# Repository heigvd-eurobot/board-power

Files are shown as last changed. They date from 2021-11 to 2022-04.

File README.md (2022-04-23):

# CRH Power Supply Board

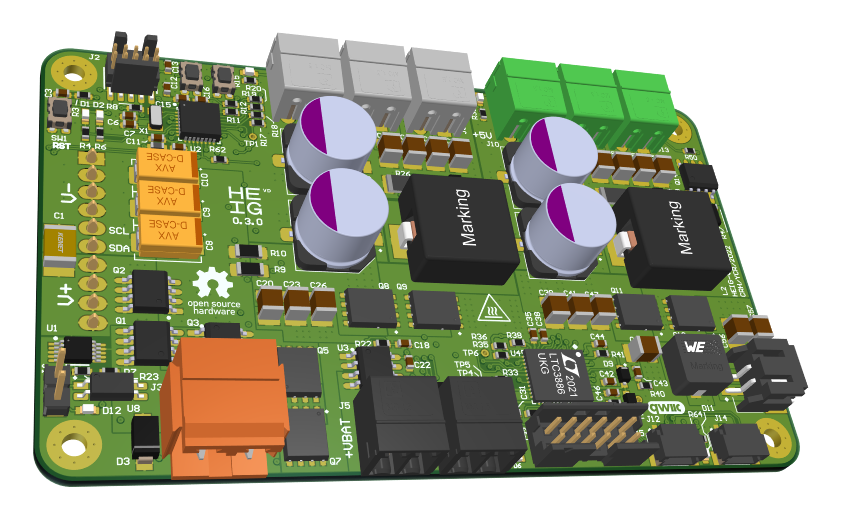
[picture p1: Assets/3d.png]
3D View


The Main Power Supply Board is a highly compact electronic board made to power up an embedded robot from a DJI Mavic 2 Battery (4-cell Li-Po) or an external power supply.

**The schematics** is available [here](Assets/schemtatics.pdf).

The board provides:

- 5 V @ 10 A Output
- 10..12 V @ 10 A Configurable Output
- 3.3 V @ 4 A Output (that may power the Qwiic System)

I2C Qwiic connectors can control the output voltages and monitor the flowing current in all outputs. An emergency switch connector will shut down all power voltages.

## Detailed specifications

- Mechanical
  - 95x58 mm
  - 4x M2.5 fixation holes
- Connectors
  - 1x 2-pin 7.62 mm External Power
  - 2x 2-pin 3.5 mm Black Battery output (on/off)
  - 2x 2-pin 3.5 mm Green 5V Output (on/off)
  - 1x 2-pin 3.5 mm Green 5V Output (on/off)
  - 3x 2-pin 3.5 mm Gray 10..12V Output (on/off)
  - 1x 12-pin LTPower debug port (For DC1613 debug probe)
  - 1x 10-pin SWD debug port for the MCU (ATSAMD20E)
  - 1x 10-pin DJI Mavic Zoom battery port
  - 1x 2-pin Emergency stop
- Pushbuttons
  - 1x Reset
  - 1x Manual Enable/disable 10..12V
  - 1x Manual Enable/disable 5V
- Monitoring
  - 5V Voltage
  - 10..12V Voltage
  - Battery voltage
  - 3.3V Voltage
  - 5V Current
  - 10..12V Current
  - Total Current consumption
  - Efficiency monitoring
  - Total Power consumption
  - I2C DJI Mavic BMS
    - Cell voltage
    - Battery cycles
    - Charge state
    - Battery life status
    - ...
- Control
  - LTC3886-1
  - ATSAMD20E
- PCB
  - 4L 6C 1.55 mm

## Revisions

### 0.1.0 Alpha (2021-10-10)

Errata:

- LTC3886 I2C address not configured (set to 0x00)
- INA381 current monitoring not working
- SCL/SDA inverted on Qwiic connectors
- Q6, Q15 should be P-MOS not N-MOS
- Missing thermal relief on most pads
- Some vias are not tamped
- Missing testpoints
- Oshpark purple PCB soldermask not good

### 0.2.0 Alpha

- Switch Frequency and phase EEPROM configured
- I2C configured by resistor
- Add testpoints
- Changed PCB color to green
- 3.3V divisor configured by E12 series instead of E96
- Add RC filter on INA381

### 0.3.0 Alpha (2022-04-23)

- Fix components absolute maximum voltage from 20ish to 40V.
- Add a I2C power monitoring and switch
- Add a 3.3V connector
- Add Hardware ESTOP (Emergency Stop) through an optocoupler
- Add ESTOP LED
- Change P-MOS switch for VBAT outputs for N-MOS
- Change the VBAT current monitoring IC for a Hall effect sensor
- Change number of layers from 4 to 6
- Fix via in pad issues with filled via (Eurocircuits option)
- Add vias in fixation holes
- Change the VEXT/VBAT switch IC for a more specialized one
- Fix LTC3886 resistors and I2C address

## Setup instructions

### Mise en service prototype

1. Supprimer R22 car le INA381 pose problème et on retrouve 4V sur pin 7
2. Éviter la série E96, R45 = 24k et R46 = 75k -> (75/24 + 1) * 0.8 = 3.3000000000000003
3. R51 à 8k2, ca devrait le faire
4. Q4 n'est pas nécessaire il empeche d'avoir de la tension sur SENSE, on peut le supprimer et mettre une zéro ohm entre S et D
5. Mettre leds vertes partout sauf sur D2 en rouge
6. Bug sur I2C, inversion SDA/SCL

Vérifier C57 ou C58 ? Hein ?

### Première mise sous tension

0. Contôle visuel sous loupe
1. Alimenter J3, limité en courant à 10mA, monter jusqu'à 15V. Vérifier la présence du 3.3V sur C58
2. Se connecter sur J9 avec le DC1613 et LTPowerPlay
3. Configurer le LTC3886
4. Se connecter sur le MCU
5. Charger un programme de base (celui qui active le 5V et le 12V)
6. Vérifier les tensions de sorties 5V et 12V
7. CC SB1 pour sauvegarder la config

## License Information

This product is **open-source**

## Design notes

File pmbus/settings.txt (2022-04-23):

#LTC PMBus Project Text File Version:1.1
#Checksum:0x6FEE
# This File is a text (machine readable) listing of all writable register values
# in your project (.proj file
# 
# NOTE: These comments are included for your benefit.  You may safely remove any line
# that starts with the character '#'
# 
# The format of this file is as follows:
# 
# Format Rules that Apply to all Versions:
#  * The first line of this file will always include a unique identifer indicating 
#    the particular version of the text file format as a comment line.
#      Example: '#LTC PMBus Project Text File Version:1.1'
# Version 1.1 format rules:
#  * The '#' character denotes a comment that should be ignored by software
#  * The next comment line (after the mandatory version line) shows the
#    checksum: 
#      Example: '#Checksum:0xAFAFAFAF'
#  * The last comment line before the register values shows the column headers: 
#      Example: '#7-Bit Address,Page,Write Protocol,Register Command Code,[DataByteHi]DataByteLo,RegisterName'
#  * Each following line contains the values for one specific register
# 
# Examples:
# 
# The following line indicates that Global Register VIN_OV_FAULT_RESPONSE_GLOBAL of the
# device at 7-bit I2C address 0x5C should be written using the Write Byte(WB)
# protocol with the command code 0x56 and the data byte 0x00
# 
# #7-Bit Address,Page,Write Protocol,Register Command Code,[DataByteHi]DataByteLo,RegisterName
# 0x5C,-1,WB,0x56,0x00,VIN_OV_FAULT_RESPONSE_GLOBAL
# 
# NOTE: The I2C transaction your software would generate is as follows:
#  * <StartCondition>
#  * 0xB8 (7-bit I2C address 0x5C with the write bit set 101 1100-0)
#  * 0x56 (The 8-bit command code for the register VIN_OV_FAULT_RESPONSE_GLOBAL)
#  * 0x00 (the data byte value for VIN_OV_FAULT_RESPONSE_GLOBAL)
#  * <StopCondition>
# NOTE: There is no need to set the PAGE register, because this is a global register
#       as indicated by Page='-1'
# NOTE: The I2C primitives necessary to execute this 'Write Byte' protocol are
#       defined in the SMBUS(TM) standard
# 
# The following line indicates the paged TON_RISE register for Page 3 of the device
# at 7-bit I2C address 0x5D should be written using the Write Word(WW) protocol with
# the command code 0x61 and the data word 0xDA80 (the low data byte byte is 0x80)
# 
# #7-Bit Address,Page,Write Protocol,Register Command Code,[DataByteHi]DataByteLo,RegisterName
# 0x5D,3,WW,0x61,0xDA80,TON_RISE
# 
# NOTE: The I2C transaction you would need to generate to write this to the device is as follows:
# 
#  * <StartCondition>
#  * 0xBA (7-bit I2C address 0x5D with the write bit set 101 1101-0)
#  * 0x00 (The 8-bit command code for the PAGE register)
#  * 0x03 (data byte indicating desired Page=3)
#  * <StopCondition>
# 
#  * <StartCondition>
#  * 0xBA (7-bit I2C address 0x5D with the write bit set 101 1101-0)
#  * 0x61 (The 8-bit command code for the global register VIN_OV_FAULT_RESPONSE_GLOBAL)
#  * 0x80 (Lo Data byte representing the desired value for the paged register TON_RISE)
#  * 0xDA (Hi Data byte representing the desired value for the paged register TON_RISE)
#  * <StopCondition>
# 
# NOTE: The I2C primitives necessary to execute this 'Write Word' protocol are defined in the SMBUS(TM) standard
# NOTE: The page register only needs to be written when you need to address a different page
# 
# 
# -----------------------------------
# NOTES ON Checksum Algorithm
# -----------------------------------
# The GUI Computes a simple 16-bit checksum for each text file it exports.
# This checksum is calculated according to the following algorithm:
# 
# Initialize the 16-bit Checksum=0
# For each line of the text file that includes a register value (like the above examples):
#   Checksum = Checksum + <7-bit address>
#   Checksum = Checksum + <page>
#   Checksum = Checksum + <command code>
#   Checksum = Checksum + <lo data byte>
#   Checksum = Checksum + <hi data byte> (add 0, or simply skip for single byte values)
# Checksum = 2's complement of Checksum
# 
# How to Verify that the Checksum is Valid when reading a text file:
# Parse the checksum reported by this file (i.e. Checksum:0xFFFD) -- call this ReportedChecksum
# Initialize a variable SumOfBytes=0
# For each line of the text file that includes a register value:
#   SumOfBytes = SumOfBytes + <7-bit address>
#   SumOfBytes = SumOfBytes + <page>
#   SumOfBytes = SumOfBytes + <command code>
#   SumOfBytes = SumOfBytes + <lo data byte>
#   SumOfBytes = SumOfBytes + <hi data byte> (add 0, or simply skip for single byte values)
# If the lowest 16-bits of SumOfBytes + ReportedChecksum == 0, the checksum is good
# Otherwise the checksum is bad.
# 
# For Example: If your SumOfBytes was computed as 0x3 and 
# the ReportedChecksum in the file was 0xFFFD.
#   0x3 + 0xFFFD = 0x10000
#   The lowest 16-bits are 0, so this cheksum is good.
# 
# 
#7-Bit Address,Page,Write Protocol,Register Command Code,[DataByteHi]DataByteLo,RegisterName
0x00,-1,WB,0x10,0x00,WRITE_PROTECT 
0x00,-1,WW,0x33,0xFABC,FREQUENCY_SWITCH_LTC3886 
0x00,-1,WW,0x35,0xD360,VIN_ON 
0x00,-1,WW,0x36,0xD320,VIN_OFF 
0x00,-1,WW,0x55,0xDA80,VIN_OV_FAULT_LIMIT 
0x00,-1,WW,0x58,0xD340,VIN_UV_WARN_LIMIT 
0x00,-1,WW,0x5D,0xDA80,IIN_OC_WARN_LIMIT 
0x00,-1,WSM,0x7C,0x00,MASK_STATUS_INPUT 
0x00,-1,WSM,0x7E,0x00,MASK_STATUS_CML 
0x00,-1,WW,0xB0,0x0000,USER_DATA_00 
0x00,-1,WW,0xB2,0x0000,USER_DATA_02 
0x00,-1,WW,0xB4,0x0000,USER_DATA_04 
0x00,-1,WB,0xD1,0x61,MFR_CONFIG_ALL_LTC3886 
0x00,-1,WB,0xE6,0x4F,MFR_ADDRESS_LTC 
0x00,-1,WW,0xE8,0xC300,MFR_IIN_CAL_GAIN_LTC 
0x00,-1,WB,0xF5,0x10,MFR_PWM_CONFIG_LTC3886 
0x00,-1,WW,0xF7,0xC300,MFR_RVIN 
0x00,0,WB,0x01,0x80,OPERATION 
0x00,0,WB,0x02,0x1E,ON_OFF_CONFIG 
0x00,0,WW,0x21,0xC000,VOUT_COMMAND 
0x00,0,WW,0x24,0xE000,VOUT_MAX 
0x00,0,WW,0x25,0xC99A,VOUT_MARGIN_HIGH 
0x00,0,WW,0x26,0xB666,VOUT_MARGIN_LOW 
0x00,0,WW,0x27,0xAA00,VOUT_TRANSITION_RATE 
0x00,0,WW,0x38,0xC300,IOUT_CAL_GAIN 
0x00,0,WW,0x40,0xD333,VOUT_OV_FAULT_LIMIT 
0x00,0,WB,0x41,0xB8,VOUT_OV_FAULT_RESPONSE 
0x00,0,WW,0x42,0xCE66,VOUT_OV_WARN_LIMIT 
0x00,0,WW,0x43,0xB19A,VOUT_UV_WARN_LIMIT 
0x00,0,WW,0x44,0xACCD,VOUT_UV_FAULT_LIMIT 
0x00,0,WB,0x45,0xB8,VOUT_UV_FAULT_RESPONSE 
0x00,0,WW,0x46,0xD300,IOUT_OC_FAULT_LIMIT 
0x00,0,WB,0x47,0x00,IOUT_OC_FAULT_RESPONSE 
0x00,0,WW,0x4A,0xD280,IOUT_OC_WARN_LIMIT 
0x00,0,WW,0x4F,0xEA80,OT_FAULT_LIMIT_PAGED 
0x00,0,WB,0x50,0xB8,OT_FAULT_RESPONSE_PAGED 
0x00,0,WW,0x51,0xEA58,OT_WARN_LIMIT_PAGED 
0x00,0,WW,0x53,0xE580,UT_FAULT_LIMIT_PAGED 
0x00,0,WB,0x54,0xB8,UT_FAULT_RESPONSE_PAGED 
0x00,0,WB,0x56,0x80,VIN_OV_FAULT_RESPONSE_PAGED 
0x00,0,WW,0x60,0x8000,TON_DELAY 
0x00,0,WW,0x61,0xD200,TON_RISE 
0x00,0,WW,0x62,0xD280,TON_MAX_FAULT_LIMIT 
0x00,0,WB,0x63,0xB8,TON_MAX_FAULT_RESPONSE 
0x00,0,WW,0x64,0x8000,TOFF_DELAY 
0x00,0,WW,0x65,0xD200,TOFF_FALL 
0x00,0,WW,0x66,0xF258,TOFF_MAX_WARN_LIMIT 
0x00,0,WSM,0x7A,0x00,MASK_STATUS_VOUT 
0x00,0,WSM,0x7B,0x00,MASK_STATUS_IOUT 
0x00,0,WSM,0x7D,0x00,MASK_STATUS_TEMP 
0x00,0,WSM,0x80,0x11,MASK_STATUS_MFR_SPECIFIC_LTC388X 
0x00,0,WW,0xB1,0x84DA,USER_DATA_01 
0x00,0,WW,0xB3,0x0000,USER_DATA_03 
0x00,0,WB,0xD0,0x1D,MFR_CHAN_CONFIG_LTC388X 
0x00,0,WW,0xD2,0x6993,MFR_GPIO__SLASH__FAULT_PROPAGATE_LTC388X 
0x00,0,WB,0xD3,0x70,MFR_PWM_COMP 
0x00,0,WB,0xD4,0xC1,MFR_PWM_MODE_LTC3886 
0x00,0,WB,0xD5,0xC0,MFR_GPIO__SLASH__FAULT_RESPONSE_LTC388X 
0x00,0,WW,0xDB,0xFABC,MFR_RETRY_DELAY_LTC_PAGED 
0x00,0,WW,0xDC,0xFBE8,MFR_RESTART_DELAY_LTC_PAGED 
0x00,0,WW,0xF6,0x0F3C,MFR_IOUT_CAL_GAIN_TC 
0x00,0,WW,0xF8,0x4000,MFR_TEMP_1_GAIN 
0x00,0,WW,0xF9,0x8000,MFR_TEMP_1_OFFSET 
0x00,0,WB,0xFA,0x80,MFR_RAIL_ADDRESS_LTC 
0x00,1,WB,0x01,0x80,OPERATION 
0x00,1,WB,0x02,0x1E,ON_OFF_CONFIG 
0x00,1,WW,0x21,0x5000,VOUT_COMMAND 
0x00,1,WW,0x24,0x5800,VOUT_MAX 
0x00,1,WW,0x25,0x5400,VOUT_MARGIN_HIGH 
0x00,1,WW,0x26,0x4C00,VOUT_MARGIN_LOW 
0x00,1,WW,0x27,0xAA00,VOUT_TRANSITION_RATE 
0x00,1,WW,0x38,0xC300,IOUT_CAL_GAIN 
0x00,1,WW,0x40,0x5800,VOUT_OV_FAULT_LIMIT 
0x00,1,WB,0x41,0xB8,VOUT_OV_FAULT_RESPONSE 
0x00,1,WW,0x42,0x5600,VOUT_OV_WARN_LIMIT 
0x00,1,WW,0x43,0x4A00,VOUT_UV_WARN_LIMIT 
0x00,1,WW,0x44,0x4800,VOUT_UV_FAULT_LIMIT 
0x00,1,WB,0x45,0xB8,VOUT_UV_FAULT_RESPONSE 
0x00,1,WW,0x46,0xD300,IOUT_OC_FAULT_LIMIT 
0x00,1,WB,0x47,0x00,IOUT_OC_FAULT_RESPONSE 
0x00,1,WW,0x4A,0xD280,IOUT_OC_WARN_LIMIT 
0x00,1,WW,0x4F,0xEAD0,OT_FAULT_LIMIT_PAGED 
0x00,1,WB,0x50,0xB8,OT_FAULT_RESPONSE_PAGED 
0x00,1,WW,0x51,0xEA58,OT_WARN_LIMIT_PAGED 
0x00,1,WW,0x53,0xE580,UT_FAULT_LIMIT_PAGED 
0x00,1,WB,0x54,0xB8,UT_FAULT_RESPONSE_PAGED 
0x00,1,WB,0x56,0x80,VIN_OV_FAULT_RESPONSE_PAGED 
0x00,1,WW,0x60,0x8000,TON_DELAY 
0x00,1,WW,0x61,0xD200,TON_RISE 
0x00,1,WW,0x62,0xD280,TON_MAX_FAULT_LIMIT 
0x00,1,WB,0x63,0xB8,TON_MAX_FAULT_RESPONSE 
0x00,1,WW,0x64,0x8000,TOFF_DELAY 
0x00,1,WW,0x65,0xD200,TOFF_FALL 
0x00,1,WW,0x66,0xF258,TOFF_MAX_WARN_LIMIT 
0x00,1,WSM,0x7A,0x00,MASK_STATUS_VOUT 
0x00,1,WSM,0x7B,0x00,MASK_STATUS_IOUT 
0x00,1,WSM,0x7D,0x00,MASK_STATUS_TEMP 
0x00,1,WSM,0x80,0x11,MASK_STATUS_MFR_SPECIFIC_LTC388X 
0x00,1,WW,0xB1,0x4A5F,USER_DATA_01 
0x00,1,WW,0xB3,0x0000,USER_DATA_03 
0x00,1,WB,0xD0,0x1D,MFR_CHAN_CONFIG_LTC388X 
0x00,1,WW,0xD2,0x6993,MFR_GPIO__SLASH__FAULT_PROPAGATE_LTC388X 
0x00,1,WB,0xD3,0x70,MFR_PWM_COMP 
0x00,1,WB,0xD4,0xC1,MFR_PWM_MODE_LTC3886 
0x00,1,WB,0xD5,0xC0,MFR_GPIO__SLASH__FAULT_RESPONSE_LTC388X 
0x00,1,WW,0xDB,0xFABC,MFR_RETRY_DELAY_LTC_PAGED 
0x00,1,WW,0xDC,0xFBE8,MFR_RESTART_DELAY_LTC_PAGED 
0x00,1,WW,0xF6,0x0F3C,MFR_IOUT_CAL_GAIN_TC 
0x00,1,WW,0xF8,0x4000,MFR_TEMP_1_GAIN 
0x00,1,WW,0xF9,0x8000,MFR_TEMP_1_OFFSET 
0x00,1,WB,0xFA,0x80,MFR_RAIL_ADDRESS_LTC

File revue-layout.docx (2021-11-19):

Carte puissance

Remarques :

- La carte est dense et il y a beaucoup de puissance à dissiper. Je n’ai pas encore eu le temps de contrôler cette partie.

# | Quand | Quoi | Résolut

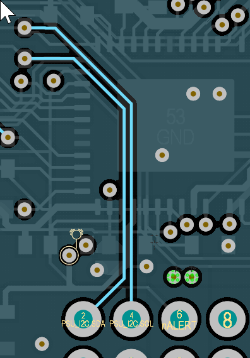
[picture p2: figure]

1 | 19.11.21 | Les pistes pour les signaux I2C ne peuvent pas aller sur la couche GND car elles auront un mauvais découplage. De plus, cela vous crée une fente qui va vous générer du bruit sur les courants de retour. | Supprimé

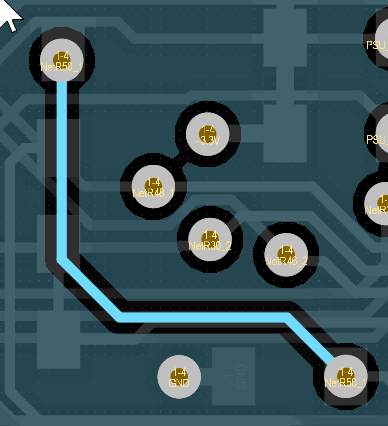
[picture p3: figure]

2 | 19.11.21 | Cette piste aussi vous crée une fente dans le plan de masse ce qui n’est vraiment pas bien. | Pas le choix, plus de place

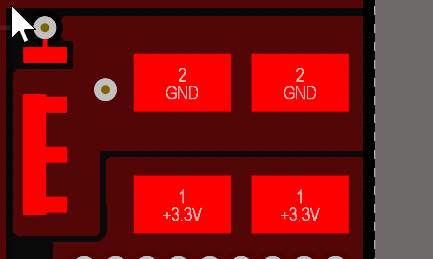
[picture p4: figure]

3 | 19.11.21 | Ici, tout le courant de retour va passer par 1 via. | Corrigé

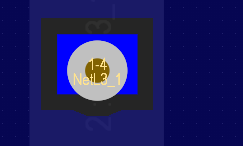
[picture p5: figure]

4 | 19.11.21 | Vous utilisez des vias in pad pour les petits composants, vous devrez donc faire attention si c’est du montage au four. | Sera monté à la main. Pas de soucis avec des trous de 0.25

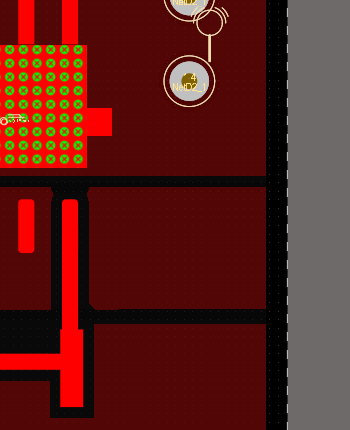
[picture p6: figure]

5 | 19.11.21 | Supprimer les zones de cuivres non connectées, cela vous évitera des antennes. | Corrigé

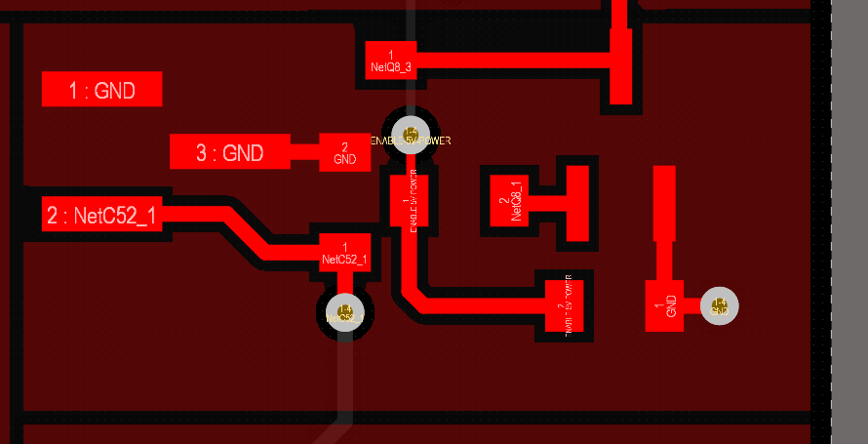
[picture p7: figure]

6 | 19.11.21 | Ce plan de masse est relié uniquement par un seul via. Ce qui veut dire que le plan n’aura pas la même équipotentialité que la couche de masse. | Corrigé

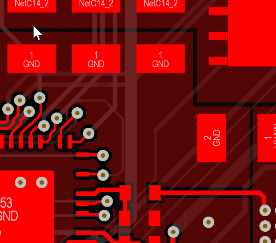
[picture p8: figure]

7 | 19.11.21 | Il manque des vias GND dans cette zone vers les gros pads des condos. | Corrigé

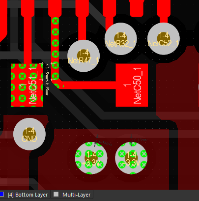
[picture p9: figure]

8 | 19.11.21 | Je pense que ces erreurs sont dues au fait que c’est une version intermédiaire. | Corrigé

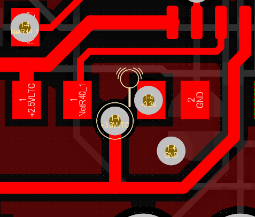
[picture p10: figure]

9 | 19.11.21 | Problème de plan pour le via 3.3VLTC | Suppression du 3.3VLTC

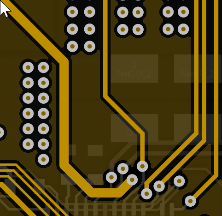
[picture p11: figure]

10 | 19.11.21 | Zone morte
11 | 19.11.21 | Il faut découpler l’alimentation 3.3 sur le connecteur J15

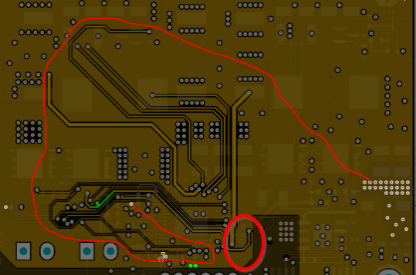
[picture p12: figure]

12 | 19.11.21 | Une partie de la zone 3.3 n’est pas bien alimentée à cause des coupures dans le plan. Le parcourt du courant pour le connecteur J15 n’est pas bon. Il faut faire une continuité de plan dans la zone indiquée par l’ovale.
13 | 19.11.21 | Il reste de la sérigraphie sur les pads. À contrôler pour le check final. | Resolu

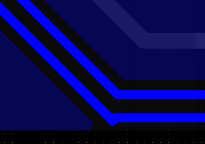
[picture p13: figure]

14 | 19.11.21 | Forme étrange sur la piste du I2C en bas de la carte. Voir s'il serait possible de séparer un peu les pistes | Resolu

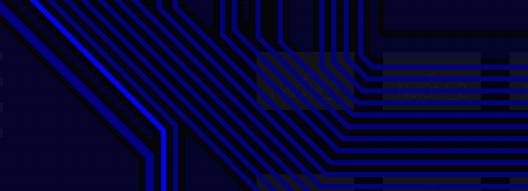
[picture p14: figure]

15 | 19.11.21 | Il est possible d’écarter un peu les pistes pour la communication (I2C) pour limiter le couplage.

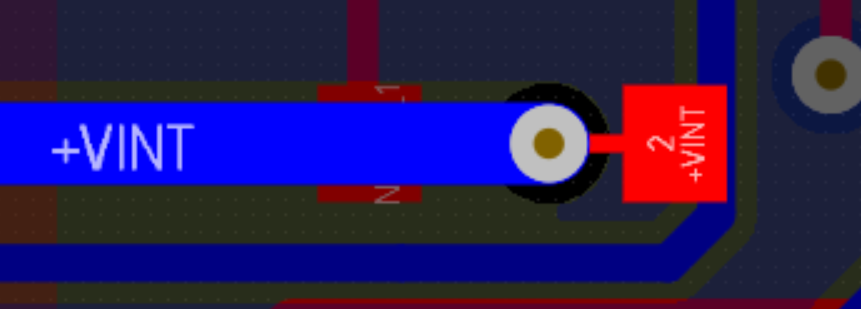
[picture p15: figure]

16 | 19.11.21 | Attention petite piste au top par rapport au bottom | Agrandi

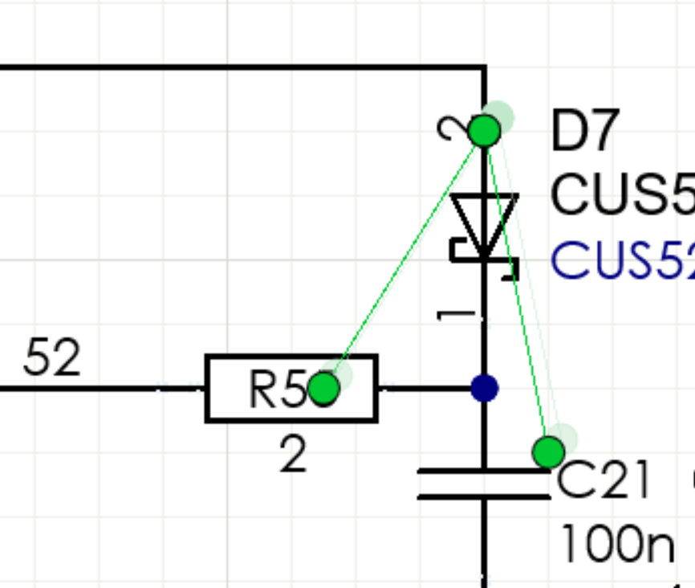
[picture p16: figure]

17 | 19.11.21 | La piste est longue pour alimenter D7, il faudrait un condo. | Ajout de condos 100n

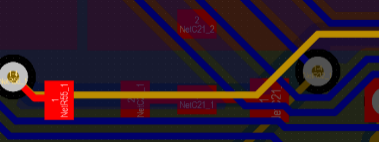
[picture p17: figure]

18 | 19.11.21 | Les pistes pour les alimenter les transistors de la branche du haut sont trop faibles. | Agrandi les pistes

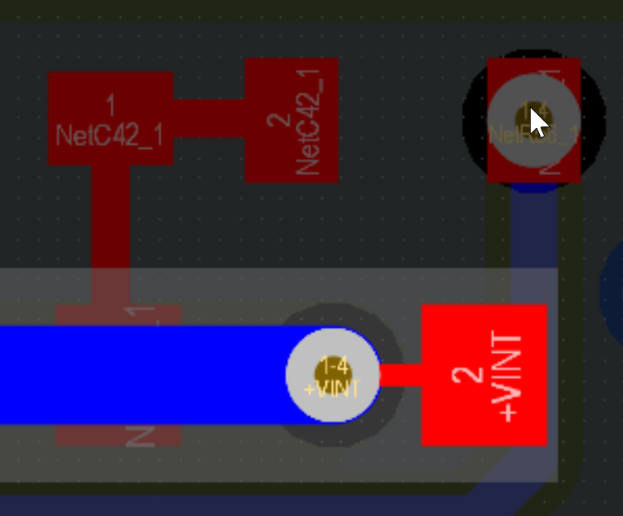
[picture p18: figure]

19 | 19.11.21 | Largeur de piste

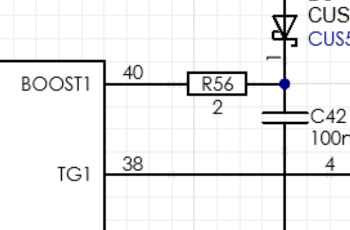
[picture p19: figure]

20 | 19.11.21 | La diode est moins importante, mais le condensateur devrait être plus près du chip

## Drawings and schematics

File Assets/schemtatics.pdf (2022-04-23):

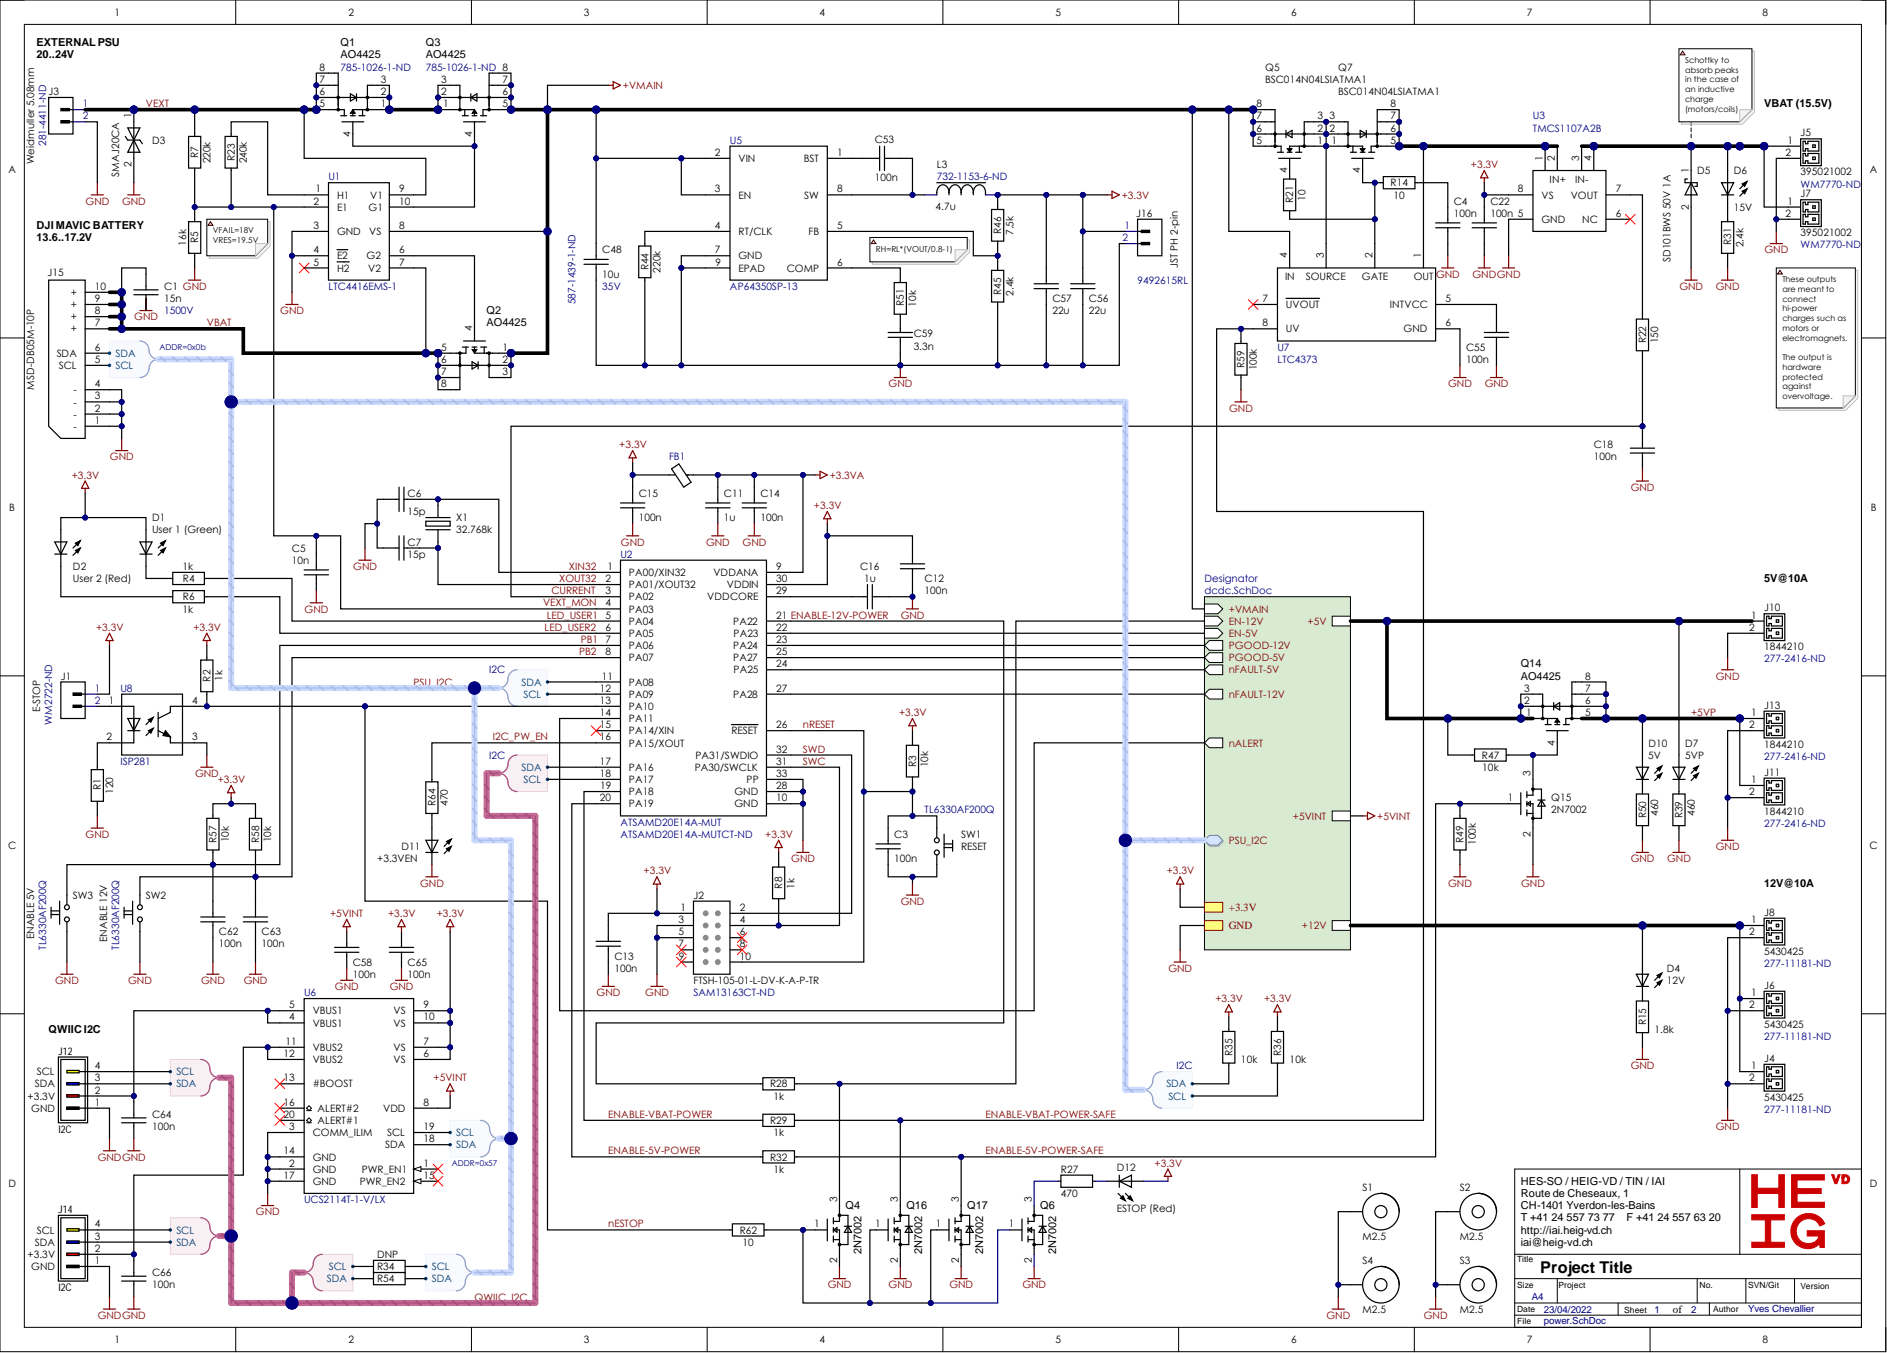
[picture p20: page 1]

Schottky to
absorb peaks
in the case of
an inductive
charge
(motors/coils)

E2 4 | RH=RL*(VOUT/0.8-1)

PA00/XIN32 1
XIN32
XOUT32 | PA01/XOUT32 2
CURRENT | PA02 3

VBUS2 12
#BOOST 13 | +5VINT

ENABLE-VBAT-POWER-SAFE

HES-SO / HEIG-VD / TIN / IAI
Route de Cheseaux, 1
CH-1401 Yverdon-les-Bains
http://iai.heig-vd.ch
iai@heig-vd.ch
Project Title

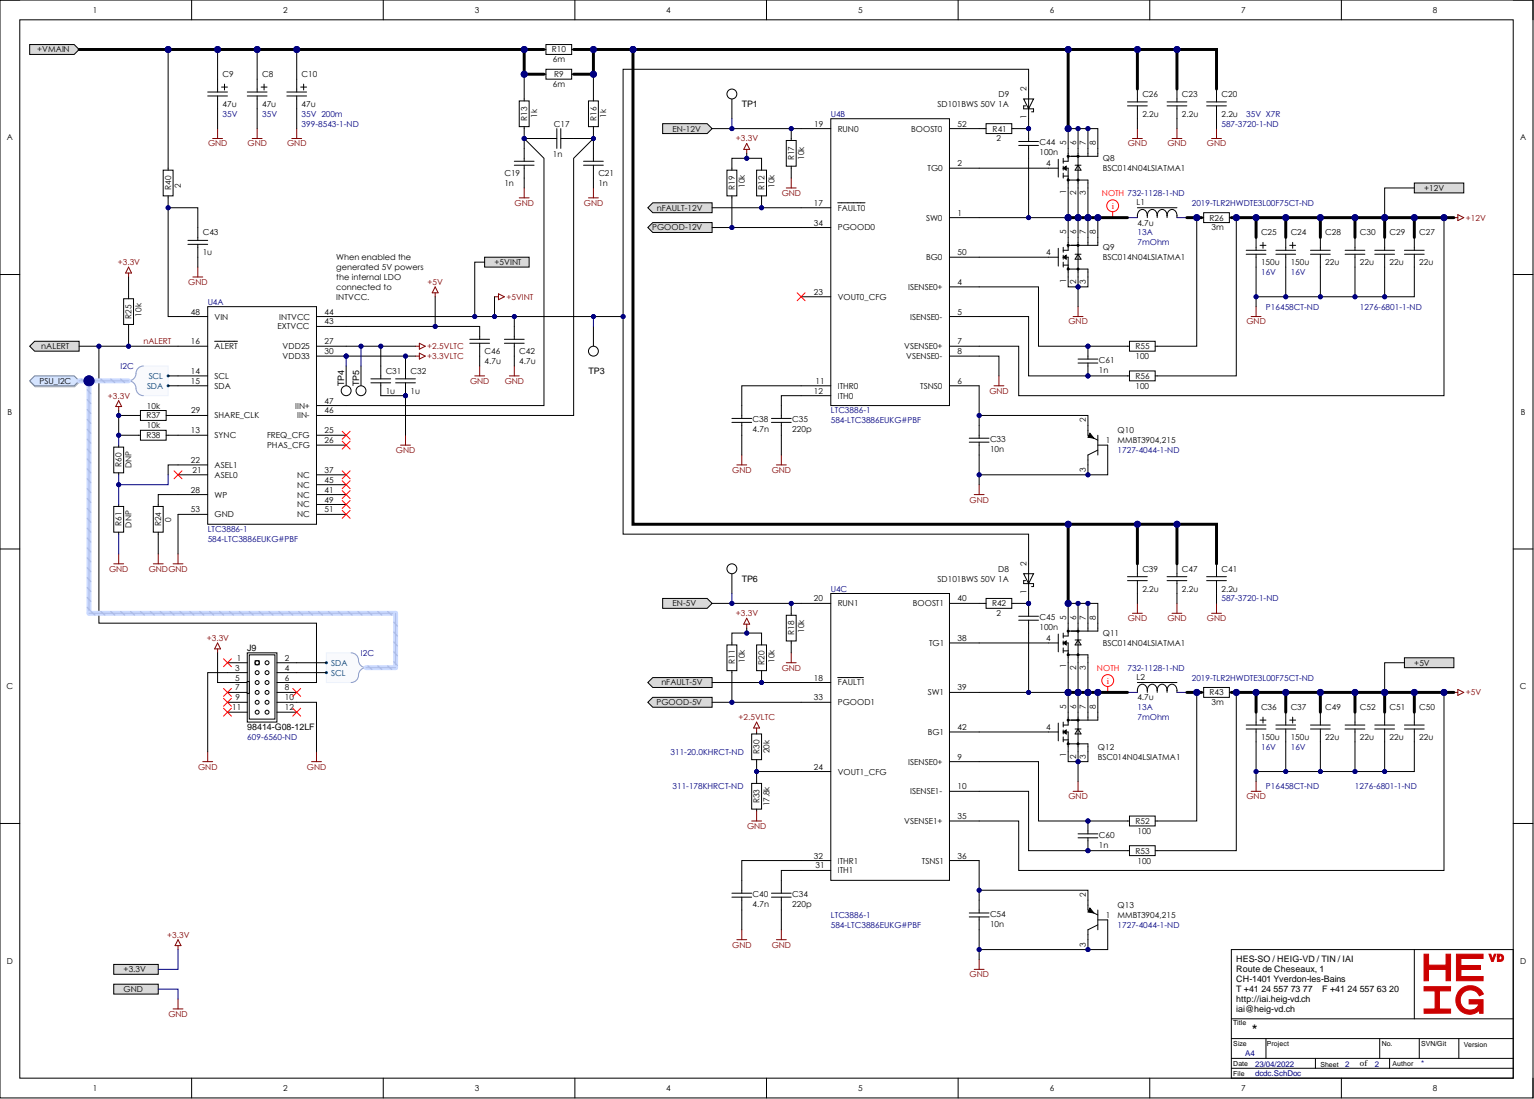
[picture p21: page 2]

ALERT 16 SCL 14 | | VSENSE0+ VSENSE0-ITHR0 11 | 7 | GND

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

Size A4 | Project | No. | SVN/Git | Version

Date 23/04/2022 | Sheet 2 of 2 | Author *

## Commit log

2021-11-16 starting bottom layer
    [Battery_PSU.PrjPcb]
2021-11-16 Preplacement almost done
    [Battery_PSU.PrjPcb, dcdc.SchDoc, power.SchDoc]
2021-11-17 Routing in progress
    [dcdc.SchDoc]
2021-11-18 Routing almost done
    [Battery_PSU.PrjPcb, dcdc.SchDoc]
2022-01-14 v0.2.0 revision start
    [dcdc.SchDoc, power.PrjPcb, power.SchDoc]
2022-04-23 v0.3.0 ready
    [dcdc.SchDoc, power.PcbLib, power.PrjPcb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]
